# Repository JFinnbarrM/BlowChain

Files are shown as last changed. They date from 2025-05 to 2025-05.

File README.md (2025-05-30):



# BlowChain: LockBox

Authors: James McAuley, Niall Waller, Dhanan Balasaravanan

Oizys - Gold

Topic: Tamper-Proof Secure-Logging Lock-Box

## Overview

Blowchain proposes an advanced digital lockbox, combining environmental sensing, offline architecture, and blockchain based accountability to remove user error from lockbox security

### System Architecture: 
- Mobile Node: Nordic Thingy 52 - The Volatile Organic Compound sensor node located inside the box, this monitors environmental parameters time and off-gassing of volatile organic compounds. 

- Mobile Node: disco_l475_iot1 - The tampering node is located inside the box with a seperate battery, this monitors environmental parameters such as magnometer and accelerometer. 

- Base Node: Receives BLE packets and uploads the data to a secure offline blockchain, checks users, inputted passwords, sensor thresholds and sends it by GATT to the PC.

- M5Core2 Display Unit: Displays a login UI with interactive buttons for each digit to enter. If the user inputs the code correctly they gain access to the lockbox.  

- Desktop Dashboard: Provides a more detailed interface for visualizing historical and live data from the VOC supply. 

- Actuator: Opens and locks the box when receving signals from the base node.

Key Features:
- Real-time BLE communication - GATT Services & Observer/Broadcaster. 
- Secure data logging using blockchain technology.
- Display UI integration with real time feedback.
- Multi-platform visualization (M5Core2, Desktop).
- Multiple sensor from different boards acting on the same system.

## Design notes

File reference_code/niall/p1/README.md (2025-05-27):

# CSSE4011 Prac 1
### _Introduction to Zephyr RTOS and ~~Bootloader~~_

#### **Niall Waller - s45819397 - Partner B**

---
## Folder Structure
repo/mycode/apps
* p1
    * t1
        * boards
            * nucleo_l496zg.overlay
        * src
            * headers.h
            * main.c
        * CMakeLists.txt
        * prj.conf
    * t2
        * boards
            * nucleo_l496zg.overlay
        * src
            * headers.h
            * main.c
        * CMakeLists.txt
        * prj.conf
    * t3
        * boards
            * nucleo_l496zg.overlay
        * src
            * headers.h
            * main.c
        * CMakeLists.txt
        * prj.conf

---
## Design Task 1
### Functionality
Full functionality achieved. The program uses a thread to generate a random number 8 digits long every 2 seconds and then passes it to a message queue primitive where it is retrieved by another thread which displays it to the terminal. The random numbers are generated using a hardware entropy device.

### Instructions
1. Assuming access to the repo folder and device USB connection onto a linux terminal in VS Code.
2. You can open a minicom terminal to view serial output using 'minicom -D /dev/ttyACM*'.
3. To build the design task use 'west build -p -b nucleo_l496zg mycode/apps/p1/t1'.
4. To flash the design task onto the device use 'west flash --runner jlink'.
5. Watch the minicom terminal for serial outputs of the random number generation every 2 seconds.
6. To see thread behaviour run the build command with the additional flags '-- -DCONFIG_QEMU_ICOUNT=n -DCONFIG_THREAD_ANALYZER=y -DCONFIG_THREAD_ANALYZER_USE_PRINTK=y -DCONFIG_THREAD_ANALYZER_AUTO=y -DCONFIG_THREAD_ANALYZER_AUTO_INTERVAL=10 -DCONFIG_THREAD_NAME=y'.

---
## Design Task 2
### Functionality
Full functionality achieved. The program uses a thread to cycle through the 8 colours in order, storing the desired colour in a message queue where another thread accesses it and activates the required GPIO pins accordingly. The setup makes use of the given NAND gate chip as a driver, and also utilises a pwm pin to control the colour and brightness of the RGB LED.

### Instructions
#### Hardware
Refer to the [ST Nucleo-L496ZG Pin Diagram](https://os.mbed.com/platforms/ST-Nucleo-L496ZG/) and [74HC03 Datasheet](https://www.ti.com/lit/ds/symlink/sn74hc03.pdf?ts=1741926828114&ref_url=https%253A%252F%252Fau.mouser.com%252F) for pin labels and connections.
1. Use a ~220 ohm resistor between the chips VCC and each of the LEDs RGB terminals to pull them up to defualt high.
2. Connect the PWM pin (PA_0) to an input of three different NAND gates on the chip.
3. Connect the RED pin (PF_0), GREEN pin (PF_1) and BLUE pin (PF_2) to the other inputs.
4. Connect the outputs of each of the three NAND gates with its respective terminal on the RGB LED.
5. Connect the GND pin on the chip to a ground terminal on the board and the GND pin on the RGB LED.
6. Connect the VCC pin on the chip to a 3V3 or 5V terminal on the board.

#### Code
1. Assuming access to the repo folder and device USB connection onto a linux terminal in VS Code.
2. You can open a minicom terminal to view serial output using 'minicom -D /dev/ttyACM*'.
3. To build the design task use 'west build -p -b nucleo_l496zg mycode/apps/p1/t1'.
4. To flash the design task onto the device use 'west flash --runner jlink'.
5. Watch the LED cycle through 8 different colours.

---
## Design Task 3
### Functionality
Full functionality achieved. The program opens a command line interface shell with the user over the sereal uart connection. From here the user has access to a command that can display the system uptime, and a command to set and toggle two of the on board LEDs. The user will also be able to see configured log messages relevant to the interface and these functions.

#### Instructions
1. Assuming access to the repo folder and device USB connection onto a linux terminal in VS Code.
2. Open a minicom terminal to view serial output using 'minicom -D /dev/ttyACM*'.
3. To build the design task use 'west build -p -b nucleo_l496zg mycode/apps/p1/t1'.
4. To flash the design task onto the device use 'west flash --runner jlink'.
5. The command line interface shell with the board will load into the minicom terminal.
6. Type the command 'help' to get a list of commands you can use from this shell interface, including two custom ones:
   1. time: allows you to view the current uptime of the system.
   2. led: allows you to set and toggle two of the boards led's
   
---
# References
---
1: Zephyr Code (including examples).

_Manually searched through for similar functionality cases._
_Searched using 'grep -r' for function usage examples._

2: Zephyr Documentation.

_Able to manually search for desired outcomes leading to the required functions._

3: Zephyr Api.

_Provided greater detail on function use and implimentation as well as providing a linking to other useful functions._

4: https://docs.zephyrproject.org/latest/boards/st/nucleo_l496zg/doc/index.html

_Zephyr Nucleo-L496ZG overview documentation provided general knowledge._

5: https://www.st.com/resource/en/user_manual/dm00368330.pdf

_Datasheet for the Nucleo-L496ZG board provided general knowledge._

---
1.1: zephyr/tests/subsys/random/rng/src/main.c

_Only provided sample code of rng I could find._

1.2: https://docs.zephyrproject.org/latest/kernel/services/index.html

_Guide on different methods of communication between threads._

1.3: https://docs.zephyrproject.org/latest/doxygen/html/group__msgq__apis.html#ga54a5cdcaea2236c383ace433fedc0d39

_API documentation for creating and using message queues._

1.4: zephyr/doc/kernel/services/data_passing/message_queues.rst

_Additional information with examples of how to create and use message queueus._

1.5: https://docs.zephyrproject.org/latest/kernel/services/threads/index.html

_Guide to the creation and usage of threads._

1.6: https://docs.zephyrproject.org/latest/doxygen/html/group__random__api.html#details

_API documentation specifying functions that can generate randomness_.

1.7: https://docs.zephyrproject.org/latest/services/crypto/random/index.html

_Guide on random number generation._

---
2.1: https://www.youtube.com/watch?v=nHu3_K9OrMg

_General tutorial on how to set up GPIO and PWM pin access using device trees._
_The best way to use a GPIO pin as an output is to configure it as an LED with 'compatible = "gpio-leds";'._
_Code for accessing and using pins is depreciated (video is 3 years old)._

2.2: /zephyr/samples/basic/blinky

_Blinky provided a perfect example on how to use GPIO pins with 'GPIO_DT_SPEC_GET' and 'gpio_pin_configure_dt' and 'gpio_pin_toggle_dt'. This directed me to the 'gpio_dt_spec' datatype._

2.3: https://docs.zephyrproject.org/latest/doxygen/html/group__gpio__interface.html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

_Here I discovered 'gpio_pin_set_dt' and 'GPIO_DT_SPEC_GET_BY_IDX' as well as formalised my knowledge on the functions used by blinky._

2.4: build/zephyr/zephyr.dts

_Looked at blinkys compiled zephyr.dts device tree for example on how its on board LED devices are configured. Copied this format with aliases and an &led node reference in my .overlay file and then checked that it had correctly transferred to the device tree afterwards._
P

2.5: https://www.justfreetools.com/en/rgb-color

_Used to determine RGB requirements to produce the required colours._

2.6 https://os.mbed.com/platforms/ST-Nucleo-L496ZG/

_Detailed and easy to read pin diagram of the board, pin selection and referencing._

2.7 https://www.ti.com/lit/ds/symlink/sn74hc03.pdf?ts=1741926828114&ref_url=https%253A%252F%252Fau.mouser.com%252F

_Datasheet for the NAND gate chip assisted with wiring._

2.8 https://www.geeksforgeeks.org/enumeration-enum-c/

_Provided background knowledge and examples on the use of enums in C programming._

2.9 zephyr/samples/basic/blinky_pwm

_Example used and adapted to create pwm device tree overlay and access/set the pin._

---
3.1 https://docs.zephyrproject.org/latest/services/shell/index.html#shell-api

_Guide to using the zephyr shell._
_Gives a simple command handler implimentation._

3.2 https://docs.zephyrproject.org/apidoc/latest/group__shell__api.html

_Details the implimentation of functions used for the zephyr shell._

3.3 zephyr/samples/subsys/shell/shell_module

_Provided code examples for creating commands for the zephyr shell._

3.4 https://docs.zephyrproject.org/latest/kernel/services/timing/clocks.html

_Guide to kernal timing access._

3.5 https://docs.zephyrproject.org/apidoc/latest/group__clock__apis.html#gae3e992cd3257c23d5b26d765fcbb2b69

_Details the implimentation of functions used for kernal timing access and modification._

3.6 https://docs.zephyrproject.org/latest/services/logging/index.html#logging-kconfig

_Zephyr documentation guide on Logging._

---

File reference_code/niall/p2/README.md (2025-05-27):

# CSSE4011 Prac 2
### _Sensor Processing, Logging and Viewing_

#### **Niall Waller - s45819397 - Partner B**

---
## Folder Structure
```
mycode/p2
├── README.md
├── t1
│   ├── mylib_clock
│   │   ├── CMakeLists.txt
│   │   ├── Kconfig
│   │   ├── include
│   │   │   └── mylib_clock_rtcc.h
│   │   ├── src
│   │   │   └── mylib_clock_rtcc.c
│   │   └── zephyr
│   │       └── module.yml
│   └── tapp
│       ├── CMakeLists.txt
│       ├── prj.conf
│       └── src
│           └── main.c
├── t2
│   ├── mylib_sensors
│   │   ├── CMakeLists.txt
│   │   ├── Kconfig
│   │   ├── boards
│   │   │   └── sltb004a.overlay
│   │   ├── include
│   │   │   ├── mylib_sensors_bmp280.h
│   │   │   ├── mylib_sensors_si1133.h
│   │   │   └── mylib_sensors_si7021.h
│   │   ├── src
│   │   │   ├── board_init.c
│   │   │   ├── mylib_sensors_bmp280.c
│   │   │   ├── mylib_sensors_si1133.c
│   │   │   └── mylib_sensors_si7021.c
│   │   └── zephyr
│   │       └── module.yml
│   └── tapp
│       ├── CMakeLists.txt
│       ├── boards
│       │   └── sltb004a.overlay
│       ├── prj.conf
│       └── src
│           └── main.c
├── t3
│   ├── mylib_shell
│   │   ├── CMakeLists.txt
│   │   ├── Kconfig
│   │   ├── include
│   │   │   └── mylib_shell_globalsh.h
│   │   ├── src
│   │   │   ├── mylib_shell_clock.c
│   │   │   └── mylib_shell_sensors.c
│   │   └── zephyr
│   │       └── module.yml
│   └── tapp
│       ├── CMakeLists.txt
│       ├── boards
│       │   └── sltb004a.overlay
│       ├── prj.conf
│       └── src
│           └── main.c
├── t4
│   ├── mylib_sampling
│   │   ├── CMakeLists.txt
│   │   ├── Kconfig
│   │   ├── boards
│   │   │   └── sltb004a.overlay
│   │   ├── include
│   │   │   ├── mylib_sampling_button.h
│   │   │   ├── mylib_sampling_json.h
│   │   │   └── mylib_sampling_thread.h
│   │   ├── src
│   │   │   ├── mylib_sampling_button.c
│   │   │   ├── mylib_sampling_json.c
│   │   │   ├── mylib_sampling_shell.c
│   │   │   └── mylib_sampling_thread.c
│   │   └── zephyr
│   │       └── module.yml
│   └── tapp
│       ├── CMakeLists.txt
│       ├── boards
│       │   └── sltb004a.overlay
│       ├── prj.conf
│       └── src
│           └── main.c
├── t5
│   ├── mylib_logfiles
│   │   ├── CMakeLists.txt
│   │   ├── Kconfig
│   │   ├── include
│   │   ├── src
│   │   └── zephyr
│   │       └── module.yml
│   └── tapp
│       ├── CMakeLists.txt
│       ├── boards
│       │   └── sltb004a.overlay
│       ├── prj.conf
│       └── src
│           └── main.c
└── t7
    ├── mylib_guipipe
    │   ├── CMakeLists.txt
    │   ├── Kconfig
    │   ├── boards
    │   │   └── sltb004a.overlay
    │   ├── include
    │   ├── src
    │   └── zephyr
    │       └── module.yml
    └── tapp
        ├── CMakeLists.txt
        ├── boards
        │   └── sltb004a.overlay
        ├── prj.conf
        └── src
            └── main.c
```
---
## Test App Project Building Instructions.
1. Assuming access to the repo folder and device USB connection onto a linux terminal in VS Code.
2. You can open a minicom terminal to view serial output using `minicom -D /dev/ttyACM*`.
3. To build the design task test app use `west build -p -b sltb004a mycode/apps/p1/t#/tapp`.
4. To flash the design task onto the device use `west flash --runner jlink`.
5. Done!

---
## Design Task 1
### Functionality
Full functionality achieved. Creates a library that allows reading from and writing to the hardware real time clock (and calendar).

### Instructions
To use the library:

1) Add this to your projects CMakeLists.txt file:
```
set(ENV{EXTRA_ZEPHYR_MODULES}
    "/home/directory/path/.../to/mylib_clock"
)
```
Note: More custom library modules can be added with a ";" seperator.

2) In your prj.conf set `CONFIG_MYLIB_CLOCK=y`.

3) Add header files.
```
#include <mylib_clock_rtcc.h>
```

You can now use the library. See the header file for function usage specifics.

Hint: Try building the t1/tapp project for an example!

---
## Design Task 2
### Functionality
Full functionality achieved for 3/4 sensor readings. Creates a library that uses threads to interface with hardware sensors allowing you to read from them without taking up main program resources.

### Instructions
To use the library:

1) Add this to your projects CMakeLists.txt file:
```
set(ENV{EXTRA_ZEPHYR_MODULES}
    "/home/directory/path/.../to/mylib_sensors"
)
```
Note: More custom library modules can be added with a ";" seperator.

2) In your prj.conf set `CONFIG_MYLIB_SENSORS=y`.

3) Add header files.
```
#include <mylib_sensors_bmp280.h>
#include <mylib_sensors_si1133.h>
#include <mylib_sensors_si7021.h>
```

4) Copy the boards folder (containing the sltb004a.overlay) file into your project directory.

You can now use the library. See the header file for function usage specifics.
Hint: Try building the t2/tapp project for an example!

---
## Design Task 3
### Functionality
Full functionality achieved. Shell commands can interface with both the clock and sensor libraries.

#### Instructions
To use the library (this one depends on other libraries!):

1) Add this to your projects CMakeLists.txt file:
```
set(ENV{EXTRA_ZEPHYR_MODULES} 
    "/home/directory/path/.../to/mylib_clock;/home/directory/path/.../to/mylib_sensors;/home/directory/path/.../to/mylib_shell;/home/directory/path/.../to/mylib_sampling"
)
```
Note: More libraries can be added with a ";" seperator.

2) In your prj.conf set:
```
CONFIG_MYLIB_CLOCK=y
CONFIG_MYLIB_SENSORS=y

CONFIG_MYLIB_SHELL=y
```

3) You will automatically have access to the shell commands. But if you want access to the shell instance used by the library called "sh_global":
```
#include <mylib_shell_globalsh>
```

4) Copy the boards folder (containing the sltb004a.overlay) file into your project directory.

You can now use the library. Type `help` into the CLI for command specifics.
Hint: Try building the t3/tapp project for an example!

---
## Design Task 4
### Functionality
Full functionality achieved. Continuous sampling can be configured using the shell. Contiuous sampling is started/stopped with a button on the board. Each sample is configured into a JSON string which can be viewed in the shell.

#### Instructions
To use the library (this one depends on other libraries!):

1) Add this to your projects CMakeLists.txt file:
```
set(ENV{EXTRA_ZEPHYR_MODULES} 
    "/home/directory/path/.../to/mylib_sensors;/home/directory/path/.../to/mylib_clock;/home/directory/path/.../to/mylib_samples"
)
```
Note: More custom library modules can be added with a ";" seperator.

2) In your prj.conf set:
```
CONFIG_MYLIB_SHELL=y
CONFIG_MYLIB_CLOCK=y
CONFIG_MYLIB_SENSORS=y

CONFIG_MYLIB_SAMPLING=y
```

3) Add header files if needed.

4) Copy the boards folder (containing the sltb004a.overlay) file into your project directory.

You can now use the library. Type `help` into the CLI for command specifics.
NOTE: THIS LIBRARYS TEST APP (TAPP) IS THE FINAL DEMO BUILD.

---
## Design Task 5
### Functionality
#### Instructions

---
## Design Task 7
### Functionality
#### Instructions

---
# References
---
## Task 1

1.1: https://www.silabs.com/documents/public/reference-manuals/efr32xg12-rm.pdf

_Wireless Gecko Reference Manual for the EFR32 chip used on the sltb004a thunderboard._
_Used to set and get from RTCC registers._

1.2: https://docs.zephyrproject.org/latest/doxygen/html/structrtc__time.html

_The rtc\_time struct reference documentation to make my library compatible with the zephyr RTC library._

1.3: modules/hal/silabs/gecko/emlib/inc/em_rtcc.h

_HAL library used to configure, get, and set from the RTCC registers._

1.3: modules/hal/silabs/gecko/emlib/inc/em_rtcc.h

_library used to check external low frequency clock was being used for RTCC._

1.4: https://edstem.org/au/courses/22383/discussion/2517796

_Ed post by Sam Kwort about file structure and CMakeLists.txt code for libraries._

1.5: https://docs.zephyrproject.org/latest/develop/modules.html#modules-without-west

_How to create modules(libraries)._

1.6: https://docs.zephyrproject.org/latest/develop/env_vars.html#env-vars

_Explains how to set the EXTRA\_ZEPHYR\_MODULES environment variable for adding your own modules_.
To set it for prac 2:
+ cp mycode/p2/.zepyrrc ~/.zephyrrc
+ source zephyr/zephyr-env.sh
Check with echo $EXTRA_ZEPHYR_MODULES

1.7: https://cmake.org/cmake/help/latest/index.html

_For understanding Cmake._

1.8: https://docs.zephyrproject.org/latest/build/cmake/index.html

_For understanding how zephyr uses CMake._

1.9: https://github.com/zephyrproject-rtos/example-application/blob/main/lib/custom/CMakeLists.txt

_Example application with a library._

1.10: https://docs.zephyrproject.org/latest/build/kconfig/index.html

_Guide to using Kconfig files for configs instead of the .config file._

1.11: https://www.tutorialspoint.com/c_standard_library/c_function_sscanf.htm

_Used to understand the sscanf() function for cmd argument parsing._

---
## Task 2

2.1: https://cmake.org/cmake/help/latest/manual/cmake-language.7.html#lists

_How to list multiple variables in a CMake environment variable (seperate with ';')._

2.2: https://www.silabs.com/documents/public/data-sheets/efr32mg12-datasheet.pdf

_EFR32MG12 Gecko Multi-Protocol Wireless SoC Family Data Sheet._

2.3: https://www.silabs.com/documents/public/schematic-files/BRD4166A-D00-schematic.pdf

_Board schematic._

2.4: https://edstem.org/au/courses/22383/discussion/2527683

_Sam's helpful ed post._

2.5: https://download.mikroe.com/documents/datasheets/Si1133.pdf

_Datasheet for si1133 (UV and Light sensor)._

2.6: https://www.silabs.com/documents/public/data-sheets/Si7021-A20.pdf

_Datasheet for si7021 (Humidity and Tempurature sensor)_.

2.7: https://www.bosch-sensortec.com/media/boschsensortec/downloads/datasheets/bst-bmp280-ds001.pdf

_Datasheet for bmp280 (Temp and Pressure sensor)._

2.8: https://docs.zephyrproject.org/latest/hardware/pinctrl/index.html

_How to name pins on the dt so that they work by default._
_Both the gas and environment sensors need the same I2C bus so have to replace the gas sensor as default or use dynamic pin control to get them to both work._

2.9: zephyr/samples/sensor/bme280

_Example usage of the bmp sensor._
_Got it working by using ed post #178 by Sam which involved setting the device tree right, using an initialising function to set the supply gpios and then removing humidity as the bmp280 doesnt have it unlike the bme280 the sample was origionally made for._

3.10: https://docs.zephyrproject.org/latest/hardware/peripherals/sensor/index.html

_How to program for sensors._

3.11: https://docs.zephyrproject.org/latest/doxygen/html/group__math__printing.html

_How to convert q31 values for printing._

3.11: https://docs.zephyrproject.org/apidoc/latest/group__spsc__lockfree.html

_SPSC message passing primitive API._

---
## Task 3

3.1: https://docs.zephyrproject.org/latest/services/shell/index.html#commands

_How to create and register shell commands with subcommands (its a heck of a lot easier than what I was doing previously)._

---
## Task 4

4.1: https://docs.zephyrproject.org/latest/doxygen/html/group__atomic__apis.html

_Atomic values._

4.2: ./zephyr/samples/basic/button

_Example of using a button._

4.3: https://github.com/zephyrproject-rtos/zephyr/blob/main/drivers/input/input_gpio_keys.c

_Driver for gpio-keys which the device tree has listed as compatible for the button nodes on my board. Its functions are used in the basic button example._

4.4: https://docs.zephyrproject.org/apidoc/latest/group__json.html

_Zephyr JSON API documentation._

4.5: ./zephyr/samples/net/secure_mqtt_sensor_actuator/src/mqtt_client.c

_Example of reading sensor values and encoding them in JSON format._

4.6: https://docs.zephyrproject.org/latest/kernel/memory_management/heap.html

_THANKYOU MALLOC._
_I needed to malloc for dynamically determined arrays._
---
## Task 5

5.1: 

---
## Task 7

7.1: 

---

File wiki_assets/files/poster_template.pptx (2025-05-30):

## BlowChain: Tamper-Proof Secure-Logging Lock-Box

- General Hints & Tips
- Do not change the colour/size/logos/positioning of the Slide Master.
- This is a standard format across all Innovation Expo posters.
- Do not add other corporate logos. This is an infringement of copyright, unless you have express permission to do so.
- Do use this space as creatively as you wish.
- Avoid using large background colours – doesn’t print well.
- Stick to the basic fonts & sizes (left) – these read clearly. If you need to reduce the text size, you are trying to put too much on your poster.
- As a check, print “scaled to fit” onto A4 and read at arms length.
- Save your poster as you work on it.
- You shouldn’t need to change the sizing of this file, it should already be landscape format with width: 41cm and height: 28.7 cm (A3 with 5 mm borders all around).
- The title may look to close to the top edge – don’t be tempted to change it. It allows for the extra 5mm from the printing.

GitHub Wiki:
Subheadings – Helvetica Neue Bold 14pt
Body Text – Helvetica Neue 14pt (min 12pt)
Don’t have the above fonts installed?
Substitutes for Bodoni MT:
Didot on Apple
or Times New Roman (Apple & Windows)
Substitutes for Helvetica Neue:
Helvetica (Apple)
or Arial (Apple & Windows)

Niall Waller, James McAuley, Dhanan Balasaravanan

What's The Problem ?
Traditional Lockboxes:
- Single shared access code → weak security & no accountability.
- Manual logs → unreliable auditing.
Digital Alternatives:
- Internet-dependent → vulnerable to remote attacks.
- Centralized databases → risk of data modification breaches.

What’s Our Solution ?
BlowChain proposes an advanced digital lockbox, combining environmental sensing, offline architecture, and blockchain based accountability to remove user error from lockbox security.

How Does it Work ?

Feature | Benefit
Human Presence Detection (CO₂ + particle sensors) | Prevents spoofing by verifying access attempt is by a human.
Blockchain Immutable Logs | Tamper-proof record of all events.
Dynamic Access Tokens (NFT-based credentials) | Time-bound, revocable permissions per user (no static codes).
Tamper Detection (Magnetometer trigger) | Alerts + logs forced entry attempts in real time.
Offline-First Design (BLE-only to base station) | No direct internet exposure → immunity to remote hacking.

What Did We Found Out ?
- Human interaction met KPI goals with registering sensor happening 98% of the time.
- GATT BLE Communication is One-To-One thus we used 1 GATT service with multiple observation/advertisers.
- Blockchain validation and performance is limited by the storage space, most blocks were
- Minting and transaction loading happened every 5 seconds with 3 transactions possible per block.

Who Needs It ?
- Real estate (secure property showings).
- Rental units (self-check-in with logs).
- Shared facilities (granular access control).
- Companies that create or access intellectual property that needs to be stored.

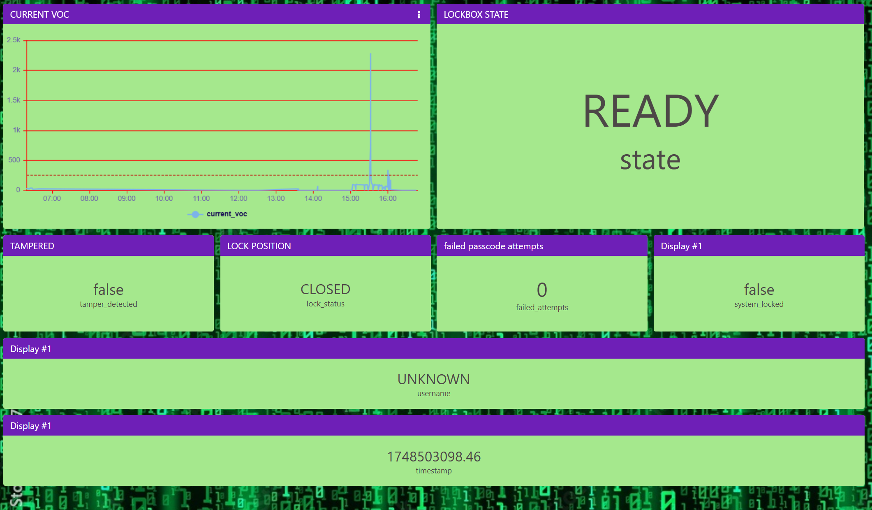
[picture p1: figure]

References & Acknowledgments
- Building Blockchain Projects – Narayan Prusty.
- Zephyr Documentation – especially Bluetooth.
- Thank you Matt, Michael & especially all the tutors for the experience.

## TITLE OF YOUR PROJECT (BODONI MT 48PT)

Your Names and Team ID (A, B, etc) (Helvetica Neue 24pt)

- MAIN HEADINGS – BODONI MT 18PT ALL CAPS
- Subheadings – Helvetica Neue Bold 14pt
- Body Text – Helvetica Neue 14pt (min 12pt)
- Don’t have the above fonts installed?
- Substitutes for Bodoni MT:
- Didot on Apple
- or Times New Roman (Apple & Windows)
- Substitutes for Helvetica Neue:
- Helvetica (Apple)
- or Arial (Apple & Windows)

- General Hints & Tips
- Do not change the colour/size/logos/positioning of the Slide Master.
- This is a standard format across all Innovation Expo posters.
- Do not add other corporate logos. This is an infringement of copyright, unless you have express permission to do so.
- Do use this space as creatively as you wish.
- Avoid using large background colours – doesn’t print well.
- Stick to the basic fonts & sizes (left) – these read clearly. If you need to reduce the text size, you are trying to put too much on your poster.
- As a check, print “scaled to fit” onto A4 and read at arms length.
- Save your poster as you work on it.
- You shouldn’t need to change the sizing of this file, it should already be landscape format with width: 41cm and height: 28.7 cm (A3 with 5 mm borders all around).
- The title may look to close to the top edge – don’t be tempted to change it. It allows for the extra 5mm from the printing.

## BlowChain: Tamper-Proof Secure-Logging Lock-Box

- General Hints & Tips
- Do not change the colour/size/logos/positioning of the Slide Master.
- This is a standard format across all Innovation Expo posters.
- Do not add other corporate logos. This is an infringement of copyright, unless you have express permission to do so.
- Do use this space as creatively as you wish.
- Avoid using large background colours – doesn’t print well.
- Stick to the basic fonts & sizes (left) – these read clearly. If you need to reduce the text size, you are trying to put too much on your poster.
- As a check, print “scaled to fit” onto A4 and read at arms length.
- Save your poster as you work on it.
- You shouldn’t need to change the sizing of this file, it should already be landscape format with width: 41cm and height: 28.7 cm (A3 with 5 mm borders all around).
- The title may look to close to the top edge – don’t be tempted to change it. It allows for the extra 5mm from the printing.

GitHub Wiki:
Subheadings – Helvetica Neue Bold 14pt
Body Text – Helvetica Neue 14pt (min 12pt)
Don’t have the above fonts installed?
Substitutes for Bodoni MT:
Didot on Apple
or Times New Roman (Apple & Windows)
Substitutes for Helvetica Neue:
Helvetica (Apple)
or Arial (Apple & Windows)

Niall Waller, James McAuley, Dhanan Balasaravanan

What’s Our Solution ?
BlowChain proposes an advanced digital lockbox, combining environmental sensing, offline architecture, and blockchain based accountability to remove user error from lockbox security.

How Does it Work ?

What's The Problem ?
Traditional Lockboxes:
- Single shared access code → weak security & no accountability.
- Manual logs → unreliable auditing.
Digital Alternatives:
- Internet-dependent → vulnerable to remote attacks.
- Centralized databases → risk of data modification breaches.

Feature | Benefit
Human Presence Detection (CO₂ + particle sensors) | Prevents spoofing by verifying access attempt is by a human.
Blockchain Immutable Logs | Tamper-proof record of all events.
Dynamic Access Tokens (NFT-based credentials) | Time-bound, revocable permissions per user (no static codes).
Tamper Detection (Magnetometer trigger) | Alerts + logs forced entry attempts in real time.
Offline-First Design (BLE-only to base station) | No direct internet exposure → immunity to remote hacking.

Who Needs It ?
- Real estate (secure property showings).
- Rental units (self-check-in with logs).
- Shared facilities (granular access control).
- Companies that create or access intellectual property that needs to be stored.

## BlowChain: Tamper-Proof Secure-Logging Lock-Box

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

GitHub Wiki:
Subheadings – Helvetica Neue Bold 14pt
Body Text – Helvetica Neue 14pt (min 12pt)
Don’t have the above fonts installed?
Substitutes for Bodoni MT:
Didot on Apple
or Times New Roman (Apple & Windows)
Substitutes for Helvetica Neue:
Helvetica (Apple)
or Arial (Apple & Windows)

Niall Waller, James McAuley, Dhanan Balasaravanan

How Does it Work ?

What's The Problem ?
Traditional Lockboxes:
- Single shared access code → weak security & no accountability.
- Manual logs → unreliable auditing.
Digital Alternatives:
- Internet-dependent → vulnerable to remote attacks.
- Centralized databases → risk of data modification breaches.

Who Would We Like To Thank ?
- Ourselves
- …
- …

What’s Our Solution ?
BlowChain proposes an advanced digital lockbox, combining environmental sensing, offline architecture, and blockchain based accountability to remove user error from lockbox security.

Who Needs It ?
- Real estate (secure property showings).
- Rental units (self-check-in with logs).
- Shared facilities (granular access control).
- Companies that create or access intellectual property that needs to be stored.

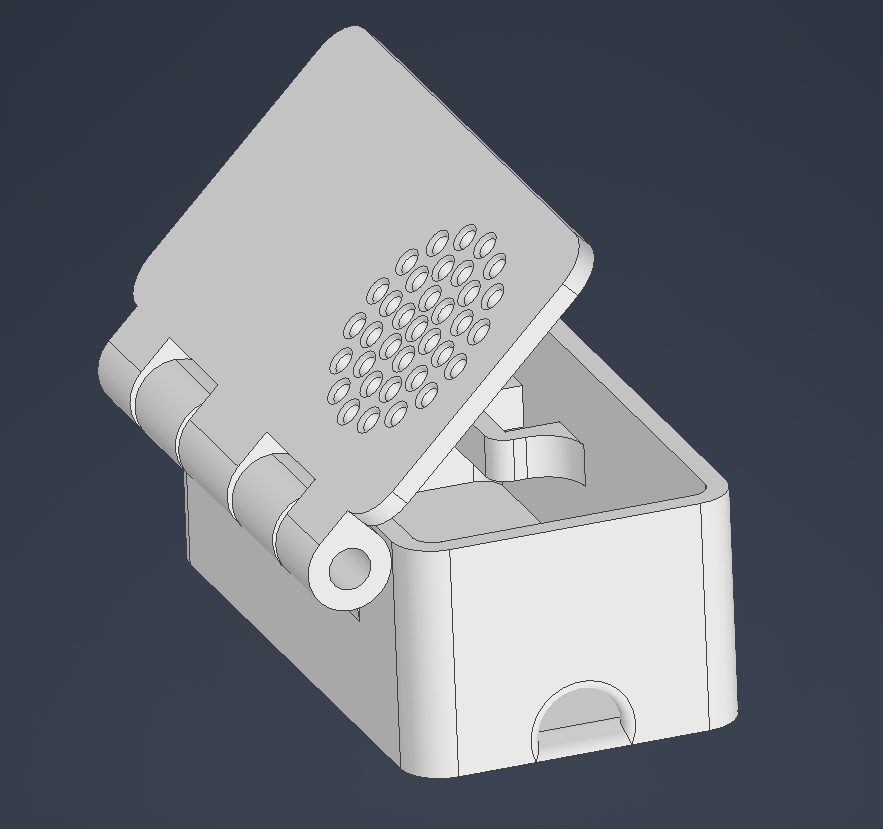
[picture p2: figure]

Feature | Benefit
Human Presence Detection (CO₂ + particle sensors) | Prevents spoofing by verifying access attempt is by a human.
Blockchain Immutable Logs | Tamper-proof record of all events.
Dynamic Access Tokens (NFT-based credentials) | Time-bound, revocable permissions per user (no static codes).
Tamper Detection (Magnetometer trigger) | Alerts + logs forced entry attempts in real time.
Offline-First Design (BLE-only to base station) | No direct internet exposure → immunity to remote hacking.

What Did We Found Out ?
- …
- …
- …

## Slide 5

## BlowChain: Tamper-Proof Secure-Logging Lock-Box

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

Niall Waller, James McAuley, Dhanan Balasaravanan

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

How Does it Work ?

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

What Did We Found Out ?
- Human interaction met KPI goals with registering sensor happening 98% of the time.
- GATT BLE Communication is One-To-One thus we used 1 GATT service with multiple observation/advertisers.
- Blockchain validation and performance is limited by the storage space, most blocks were
- Minting and transaction loading happened every 5 seconds with 3 transactions possible per block.

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

References & Acknowledgments
- Building Blockchain Projects – Narayan Prusty.
- Zephyr Documentation – especially Bluetooth.
- Thank you Matt, Michael & especially all the tutors for the experience.

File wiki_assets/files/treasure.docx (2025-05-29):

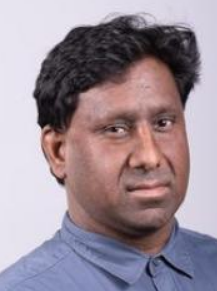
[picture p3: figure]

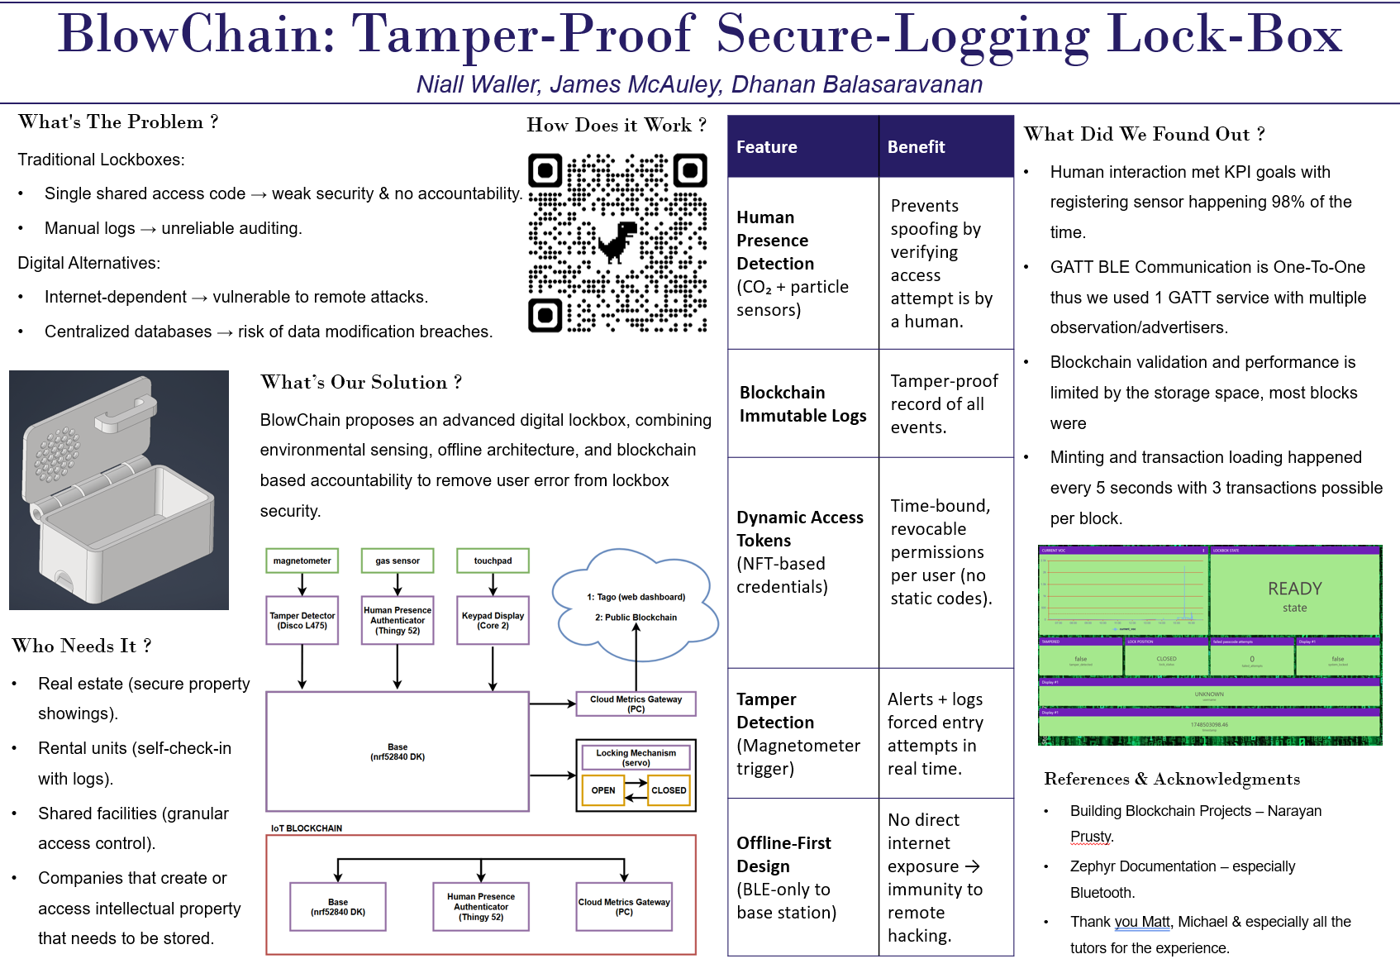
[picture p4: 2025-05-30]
wiki_assets/poster.png

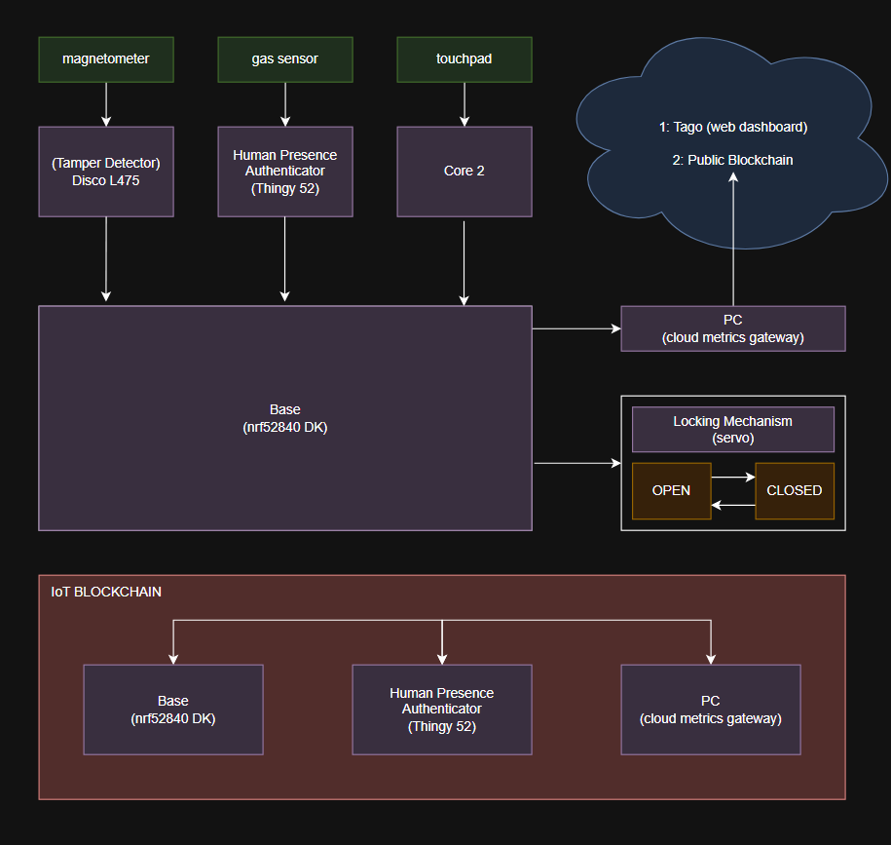
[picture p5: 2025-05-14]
wiki_assets/LockBox_BlockDiagram.png

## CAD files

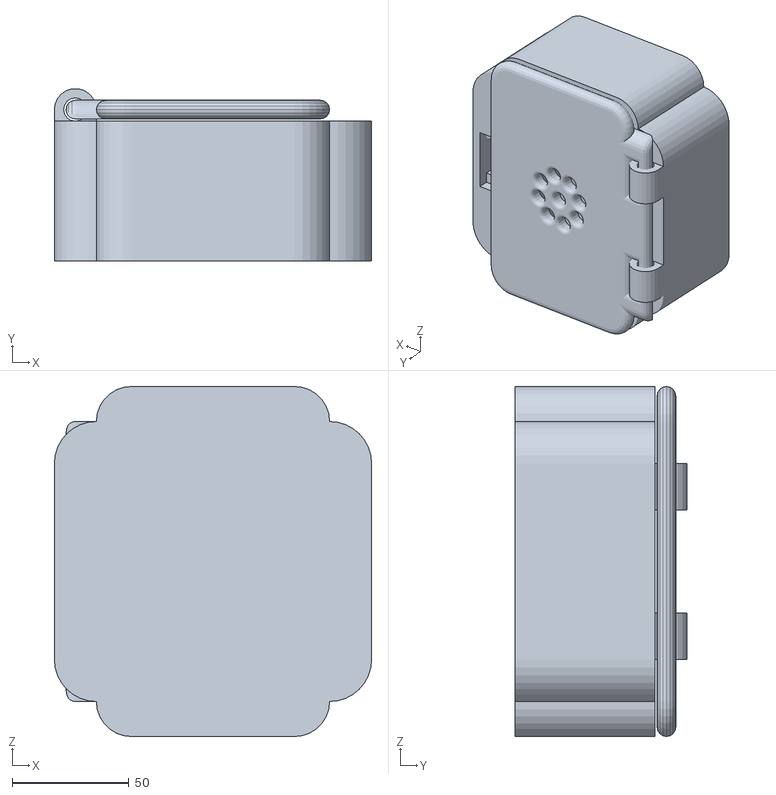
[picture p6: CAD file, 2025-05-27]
wiki_assets/files/inventor/one/assembly_p1.stl
136.0 x 73.9 x 150.0

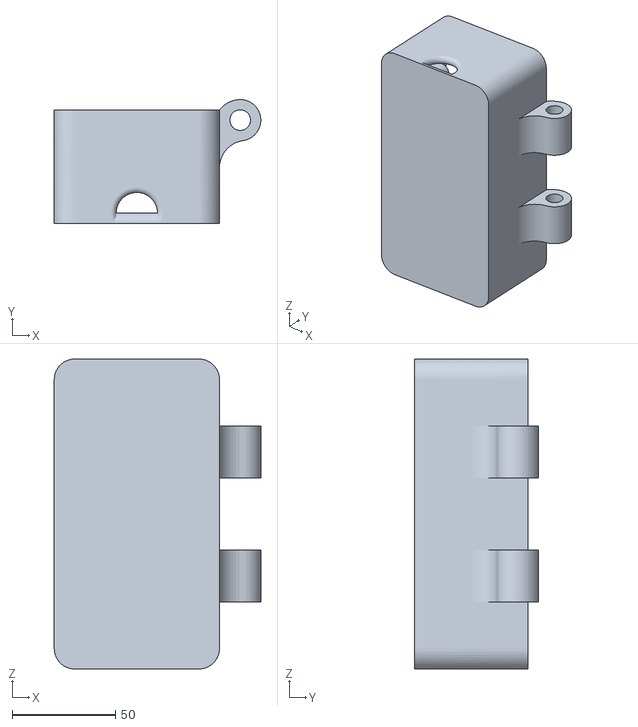
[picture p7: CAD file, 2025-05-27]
wiki_assets/files/inventor/two/box2.stl
100.0 x 60.0 x 150.0

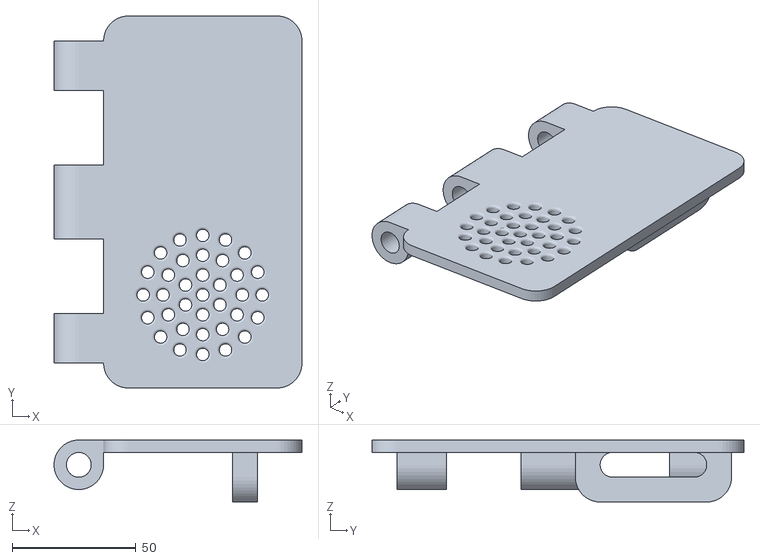
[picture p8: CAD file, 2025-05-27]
wiki_assets/files/inventor/two/lid2.stl
100.0 x 150.0 x 25.0

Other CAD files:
wiki_assets/files/OldVersions/box.0001.ipt
wiki_assets/files/inventor/OldVersions/assembly.0001.iam
wiki_assets/files/inventor/OldVersions/box.0006.ipt
wiki_assets/files/inventor/one/assembly.iam
wiki_assets/files/inventor/one/box.ipt
wiki_assets/files/inventor/one/lid.ipt
wiki_assets/files/inventor/two/OldVersions/assembly2.0004.iam
wiki_assets/files/inventor/two/OldVersions/box2.0004.ipt
wiki_assets/files/inventor/two/OldVersions/lid2.0004.ipt
wiki_assets/files/inventor/two/assembly2.iam
wiki_assets/files/inventor/two/box2.ipt
wiki_assets/files/inventor/two/lid2.ipt

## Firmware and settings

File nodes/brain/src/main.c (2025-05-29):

#include "lock.h"
#include "zephyr/bluetooth/gap.h"
#include <zephyr/kernel.h>
#include <zephyr/device.h>
#include <zephyr/fs/fs.h>
#include <zephyr/fs/littlefs.h>
#include <zephyr/storage/flash_map.h>
#include <zephyr/logging/log.h>
#include <zephyr/shell/shell.h>
#include <zephyr/bluetooth/bluetooth.h>
#include <zephyr/bluetooth/gatt.h>
#include <zephyr/bluetooth/uuid.h>
#include <string.h>
#include <stdio.h>
#include <stdlib.h>

LOG_MODULE_REGISTER(blockchain, LOG_LEVEL_INF);

static char* static_mac_str =  "dc:80:00:00:08:35";

#define MAX_TRANSACTIONS_PER_BLOCK 3
#define MAX_USER_ID_LEN 16
#define MAX_DATA_LEN 32
#define BLOCKCHAIN_FILE "/lfs/chain.dat"
#define MAX_BLOCKS 20
#define HASH_SIZE 8
#define MAX_FAILED_ATTEMPTS 3
#define PASSCODE_LEN 6
#define MAX_BLE_CONNECTIONS 4

// Multi-user support definitions
#define MAX_USERS 10
#define PASSCODE_EXPIRE_TIME_MS (5 * 60 * 1000)  // 5 minutes

#define BT_UUID_LOCKBOX_SERVICE      BT_UUID_DECLARE_16(0x1234)
#define BT_UUID_USERNAME             BT_UUID_DECLARE_16(0xAA01)
#define BT_UUID_BLOCK_INFO           BT_UUID_DECLARE_16(0xBB02)
#define BT_UUID_LOCK_STATUS          BT_UUID_DECLARE_16(0xCC03)
#define BT_UUID_USER_STATUS          BT_UUID_DECLARE_16(0xDD04)
#define BT_UUID_PASSCODE             BT_UUID_DECLARE_16(0xEE05)
#define BT_UUID_VOC_SENSOR           BT_UUID_DECLARE_16(0xFF06)
#define BT_UUID_TAMPER_CONTROL       BT_UUID_DECLARE_16(0x1107)  // NEW: Tamper control

static bool verbose = false;

typedef enum {
    TX_USER_ADDED = 1,
    TX_ACCESS_GRANTED,
    TX_ACCESS_DENIED,
    TX_PRESENCE_DETECTED,
    TX_PASSCODE_GENERATED,
    TX_PASSCODE_VERIFIED,
    TX_PASSCODE_FAILED,
    TX_TAMPER_DETECTED,
    TX_SYSTEM_LOCKED,
    TX_SYSTEM_STARTUP,
    TX_SYSTEM_SHUTDOWN
} transaction_type_t;

typedef enum {
    STATE_READY = 0,
    STATE_PRESENCE_DETECTED,
    STATE_WAITING_PASSCODE,
    STATE_LOCKED,
    STATE_SHUTDOWN
} system_state_t;

typedef enum {
    CLIENT_TYPE_UNKNOWN = 0,
    CLIENT_TYPE_PC,
    CLIENT_TYPE_VOC_SENSOR
} client_type_t;

typedef struct {
    uint32_t timestamp;
    transaction_type_t type;
    char user_id[MAX_USER_ID_LEN];
    char data[MAX_DATA_LEN];
    uint32_t hash;
} simple_transaction_t;

typedef struct {
    uint32_t id;
    uint32_t timestamp;
    uint32_t prev_hash;
    uint32_t nonce;
    uint16_t tx_count;
    simple_transaction_t transactions[MAX_TRANSACTIONS_PER_BLOCK];
    uint32_t block_hash;
} simple_block_t;

typedef struct {
    uint32_t total_blocks;
    uint32_t latest_hash;
    simple_block_t blocks[MAX_BLOCKS];
} blockchain_data_t;

typedef struct {
    system_state_t state;
    char current_passcode[PASSCODE_LEN + 1];
    char current_user[MAX_USER_ID_LEN];
    uint32_t failed_attempts;
    uint32_t passcode_timestamp;
    bool tamper_detected;
    bool system_locked;
    bool system_shutdown;  // NEW: System shutdown flag
} lockbox_state_t;

typedef struct {
    struct bt_conn *conn;
    client_type_t type;
    char identifier[16];
    uint32_t last_activity;
    bool is_active;
    bool voc_notifications_enabled;
    bool status_notifications_enabled;
    bool lock_notifications_enabled;
    bool block_notifications_enabled;
} connection_info_t;

typedef struct {
    char user_id[MAX_USER_ID_LEN];
    char passcode[PASSCODE_LEN + 1]; 
    uint32_t timestamp;
    bool is_active;
} user_entry_t;

typedef struct {
    user_entry_t users[MAX_USERS];
    int active_user_count;
} user_table_t;

// Bluetooth stuff
static const bt_addr_le_t mac_addr_thing = {
    .type = BT_ADDR_LE_RANDOM,
    .a = {.val = {0xFF, 0xAA, 0xFF, 0xAA, 0xFF, 0xDA}}
};

static const bt_addr_le_t mac_addr_disco = {
    .type = BT_ADDR_LE_RANDOM,
    .a = {.val = {0xFF, 0xCC, 0xBB, 0xCC, 0xBB, 0xDA}}
};

static const bt_addr_le_t mac_addr_core = {
    .type = BT_ADDR_LE_RANDOM,
    .a = {.val = {0xFF, 0xCC, 0xBC, 0xBB, 0xAA, 0xDA}}
};

struct sensor_data {
    int x;
    int y;
    int z;
    int xf;
    int yf;
    int zf;
};

static blockchain_data_t g_blockchain;
static lockbox_state_t g_lockbox_state = {0};
static struct k_mutex blockchain_mutex;
static struct k_mutex lockbox_mutex;
static struct k_msgq pending_tx_queue;
static simple_transaction_t pending_tx_buffer[10];
static char current_username[MAX_USER_ID_LEN] = "UNKNOWN";

// Multi-user globals
static user_table_t g_user_table = {0};
static struct k_mutex user_table_mutex;

#define VOC_PRESENCE_THRESHOLD 250
#define MAG_PRESENCE_THRESHOLD 250
#define ACC_PRESENCE_THRESHOLD 250
static connection_info_t connections[MAX_BLE_CONNECTIONS];
static struct k_mutex connections_mutex;

static uint16_t current_voc_value = 0;
static uint32_t last_voc_timestamp = 0;

static uint16_t current_avg_acc_value = 0;
static uint16_t current_avg_mag_value = 0;

// Global shutdown flag for threads
static volatile bool system_shutdown_requested = false;

static int create_genesis_block(void);
static int save_blockchain(void);
static int load_blockchain(void);
static void send_alert_to_dashboard(const char *message);
static int reset_blockchain(void);
static int validate_blockchain(void);
static void trigger_system_shutdown(const char *reason);  // NEW: System shutdown function

// Connection management function declarations
static int find_free_connection_slot(void);
static int find_connection_by_handle(struct bt_conn *conn);
static void update_connection_activity(struct bt_conn *conn);
static client_type_t get_connection_type(struct bt_conn *conn);
static void set_connection_type(struct bt_conn *conn, client_type_t type, const char *identifier);

// Blockchain function declarations
static int add_transaction(transaction_type_t type, const char *user_id, const char *data);

// Multi-user function declarations
static int find_user_index(const char *user_id);
static int find_free_user_slot(void);
static void cleanup_expired_passcodes(void);
static void generate_passcode(const char *user_id);
static bool verify_passcode(const char *user_id, const char *entered_code);

FS_LITTLEFS_DECLARE_DEFAULT_CONFIG(storage);
static struct fs_mount_t blockchain_fs_mount = {
    .type = FS_LITTLEFS,
    .fs_data = &storage,
    .storage_dev = (void *)FIXED_PARTITION_ID(storage_partition),
    .mnt_point = "/lfs",
};

// Forward declarations for GATT handlers
static ssize_t write_voc_sensor(struct bt_conn *conn, const struct bt_gatt_attr *attr,
                               const void *buf, uint16_t len, uint16_t offset, uint8_t flags);
static ssize_t read_voc_sensor(struct bt_conn *conn, const struct bt_gatt_attr *attr,
                                void *buf, uint16_t len, uint16_t offset);
static ssize_t write_username(struct bt_conn *conn, const struct bt_gatt_attr *attr, 
                             const void *buf, uint16_t len, uint16_t offset, uint8_t flags);
static ssize_t read_username(struct bt_conn *conn, const struct bt_gatt_attr *attr,
                            void *buf, uint16_t len, uint16_t offset);
static ssize_t read_block_info(struct bt_conn *conn, const struct bt_gatt_attr *attr,
                              void *buf, uint16_t len, uint16_t offset);
static ssize_t read_lock_status(struct bt_conn *conn, const struct bt_gatt_attr *attr,
                               void *buf, uint16_t len, uint16_t offset);
static ssize_t read_user_status(struct bt_conn *conn, const struct bt_gatt_attr *attr,
                               void *buf, uint16_t len, uint16_t offset);
static ssize_t write_passcode(struct bt_conn *conn, const struct bt_gatt_attr *attr,
                             const void *buf, uint16_t len, uint16_t offset, uint8_t flags);
static ssize_t read_passcode(struct bt_conn *conn, const struct bt_gatt_attr *attr,
                            void *buf, uint16_t len, uint16_t offset);
// NEW: Tamper control handlers
static ssize_t write_tamper_control(struct bt_conn *conn, const struct bt_gatt_attr *attr,
                                   const void *buf, uint16_t len, uint16_t offset, uint8_t flags);
static ssize_t read_tamper_control(struct bt_conn *conn, const struct bt_gatt_attr *attr,
                                  void *buf, uint16_t len, uint16_t offset);

// GATT Service Definition - Updated with tamper control
BT_GATT_SERVICE_DEFINE(lockbox_svc,
    BT_GATT_PRIMARY_SERVICE(BT_UUID_LOCKBOX_SERVICE),
    
    BT_GATT_CHARACTERISTIC(BT_UUID_USERNAME, 
        BT_GATT_CHRC_READ | BT_GATT_CHRC_WRITE,
        BT_GATT_PERM_READ | BT_GATT_PERM_WRITE,
        read_username, write_username, NULL),
        
    BT_GATT_CHARACTERISTIC(BT_UUID_BLOCK_INFO,
        BT_GATT_CHRC_READ,
        BT_GATT_PERM_READ,
        read_block_info, NULL, NULL),
        
    BT_GATT_CHARACTERISTIC(BT_UUID_LOCK_STATUS,
        BT_GATT_CHRC_READ,
        BT_GATT_PERM_READ,
        read_lock_status, NULL, NULL),
        
    BT_GATT_CHARACTERISTIC(BT_UUID_USER_STATUS,
        BT_GATT_CHRC_READ,
        BT_GATT_PERM_READ,
        read_user_status, NULL, NULL),
        
    BT_GATT_CHARACTERISTIC(BT_UUID_PASSCODE,
        BT_GATT_CHRC_READ | BT_GATT_CHRC_WRITE,
        BT_GATT_PERM_READ | BT_GATT_PERM_WRITE,
        read_passcode, write_passcode, NULL),
        
    BT_GATT_CHARACTERISTIC(BT_UUID_VOC_SENSOR,
        BT_GATT_CHRC_READ | BT_GATT_CHRC_WRITE,
        BT_GATT_PERM_READ | BT_GATT_PERM_WRITE,
        read_voc_sensor, write_voc_sensor, NULL),
        
    // NEW: Tamper control characteristic
    BT_GATT_CHARACTERISTIC(BT_UUID_TAMPER_CONTROL,
        BT_GATT_CHRC_READ | BT_GATT_CHRC_WRITE,
        BT_GATT_PERM_READ | BT_GATT_PERM_WRITE,
        read_tamper_control, write_tamper_control, NULL),
);

static const struct bt_data ad[] = {
    BT_DATA_BYTES(BT_DATA_FLAGS, BT_LE_AD_GENERAL | BT_LE_AD_NO_BREDR),
    BT_DATA_BYTES(BT_DATA_NAME_COMPLETE, "SecureLockbox"),
    BT_DATA_BYTES(BT_DATA_UUID16_ALL, 0x34, 0x12),
};

static char* find_user_by_passcode(const char *passcode) {
    static char found_user_id[MAX_USER_ID_LEN];
    
    k_mutex_lock(&user_table_mutex, K_FOREVER);
    
    // Clean up expired passcodes first
    cleanup_expired_passcodes();
    
    for (int i = 0; i < MAX_USERS; i++) {
        if (g_user_table.users[i].is_active && 
            strcmp(g_user_table.users[i].passcode, passcode) == 0) {
            strncpy(found_user_id, g_user_table.users[i].user_id, MAX_USER_ID_LEN - 1);
            found_user_id[MAX_USER_ID_LEN - 1] = '\0';
            k_mutex_unlock(&user_table_mutex);
            return found_user_id;
        }
    }
    
    k_mutex_unlock(&user_table_mutex);
    return NULL;
}

// Multi-user helper functions
static int find_user_index(const char *user_id) {
    for (int i = 0; i < MAX_USERS; i++) {
        if (g_user_table.users[i].is_active && 
            strcmp(g_user_table.users[i].user_id, user_id) == 0) {
            return i;
        }
    }
    return -1;
}

static int find_free_user_slot(void) {
    for (int i = 0; i < MAX_USERS; i++) {
        if (!g_user_table.users[i].is_active) {
            return i;
        }
    }
    return -1;
}

static void cleanup_expired_passcodes(void) {
    uint32_t current_time = k_uptime_get_32();
    
    for (int i = 0; i < MAX_USERS; i++) {
        if (g_user_table.users[i].is_active) {
            uint32_t age = current_time - g_user_table.users[i].timestamp;
            if (age > PASSCODE_EXPIRE_TIME_MS) {
                LOG_INF("Passcode expired for user: %s", g_user_table.users[i].user_id);
                memset(&g_user_table.users[i], 0, sizeof(user_entry_t));
                g_user_table.active_user_count--;
            }
        }
    }
}

// Connection management functions
static int find_free_connection_slot(void) {
    for (int i = 0; i < MAX_BLE_CONNECTIONS; i++) {
        if (!connections[i].is_active) {
            return i;
        }
    }
    return -1;
}

static int find_connection_by_handle(struct bt_conn *conn) {
    for (int i = 0; i < MAX_BLE_CONNECTIONS; i++) {
        if (connections[i].is_active && connections[i].conn == conn) {
            return i;
        }
    }
    return -1;
}

static void update_connection_activity(struct bt_conn *conn) {
    k_mutex_lock(&connections_mutex, K_FOREVER);
    int slot = find_connection_by_handle(conn);
    if (slot >= 0) {
        connections[slot].last_activity = k_uptime_get_32();
    }
    k_mutex_unlock(&connections_mutex);
}

static client_type_t get_connection_type(struct bt_conn *conn) {
    k_mutex_lock(&connections_mutex, K_FOREVER);
    int slot = find_connection_by_handle(conn);
    client_type_t type = (slot >= 0) ? connections[slot].type : CLIENT_TYPE_UNKNOWN;
    k_mutex_unlock(&connections_mutex);
    return type;
}

static void set_connection_type(struct bt_conn *conn, client_type_t type, const char *identifier) {
    k_mutex_lock(&connections_mutex, K_FOREVER);
    int slot = find_connection_by_handle(conn);
    if (slot >= 0) {
        LOG_INF("=== SETTING CONNECTION TYPE ===");
        LOG_INF("Slot: %d", slot);
        LOG_INF("Old type: %d (%s)", connections[slot].type, connections[slot].identifier);
        LOG_INF("New type: %d (%s)", type, identifier);
        
        connections[slot].type = type;
        strncpy(connections[slot].identifier, identifier, sizeof(connections[slot].identifier) - 1);
        connections[slot].identifier[sizeof(connections[slot].identifier) - 1] = '\0';
        connections[slot].last_activity = k_uptime_get_32();
        
        LOG_INF("*** Connection %d identified as %s ***", slot, identifier);
    } else {
        LOG_ERR("Failed to find connection for type setting");
    }
    k_mutex_unlock(&connections_mutex);
}

// Hash and blockchain functions (simplified for space)
static uint32_t simple_hash(const void *data, size_t len) {
    const uint8_t *bytes = (const uint8_t *)data;
    uint32_t hash = 0x811c9dc5;
    for (size_t i = 0; i < len; i++) {
        hash ^= bytes[i];
        hash *= 0x01000193;
    }
    return hash;
}

static int add_transaction(transaction_type_t type, const char *user_id, const char *data) {
    if (system_shutdown_requested && type != TX_SYSTEM_SHUTDOWN) {
        return -ESHUTDOWN;
    }
    
    simple_transaction_t tx;
    tx.timestamp = k_uptime_get_32();
    tx.type = type;
    strncpy(tx.user_id, user_id, MAX_USER_ID_LEN - 1);
    tx.user_id[MAX_USER_ID_LEN - 1] = '\0';
    strncpy(tx.data, data, MAX_DATA_LEN - 1);
    tx.data[MAX_DATA_LEN - 1] = '\0';
    tx.hash = simple_hash(&tx, sizeof(simple_transaction_t) - sizeof(tx.hash));
    
    int ret = k_msgq_put(&pending_tx_queue, &tx, K_NO_WAIT);
    if (ret < 0) {
        LOG_ERR("Transaction queue full");
        return ret;
    }
    LOG_INF("Transaction added: %s - %s", user_id, data);
    return 0;
}

static void trigger_system_shutdown(const char *reason) {
    LOG_ERR("=== INITIATING SYSTEM SHUTDOWN ===");
    LOG_ERR("Reason: %s", reason);
    
    k_mutex_lock(&lockbox_mutex, K_FOREVER);
    g_lockbox_state.tamper_detected = true;
    g_lockbox_state.system_locked = true;
    g_lockbox_state.system_shutdown = true;
    g_lockbox_state.state = STATE_SHUTDOWN;
    k_mutex_unlock(&lockbox_mutex);
    
    system_shutdown_requested = true;
    
    add_transaction(TX_SYSTEM_SHUTDOWN, "SYSTEM", reason);
=
    lock_close();
    
    k_mutex_lock(&connections_mutex, K_FOREVER);
    for (int i = 0; i < MAX_BLE_CONNECTIONS; i++) {
        if (connections[i].is_active) {
            LOG_WRN("Disconnecting BLE client: %s", connections[i].identifier);
            bt_conn_disconnect(connections[i].conn, BT_HCI_ERR_REMOTE_USER_TERM_CONN);
            bt_conn_unref(connections[i].conn);
            memset(&connections[i], 0, sizeof(connection_info_t));
        }
    }
    k_mutex_unlock(&connections_mutex);
    
    bt_le_adv_stop();

    send_alert_to_dashboard("CRITICAL: System shutdown initiated - All operations halted");
    
    LOG_ERR("=== SYSTEM SHUTDOWN COMPLETE ===");
    LOG_ERR("All operations halted. System requires physical reset.");
}

static ssize_t write_tamper_control(struct bt_conn *conn, const struct bt_gatt_attr *attr,
                                   const void *buf, uint16_t len, uint16_t offset, uint8_t flags) {
    if (len != 1) {
        return BT_GATT_ERR(BT_ATT_ERR_INVALID_ATTRIBUTE_LEN);
    }
    
    // Check if system is already shutdown
    k_mutex_lock(&lockbox_mutex, K_FOREVER);
    bool already_shutdown = g_lockbox_state.system_shutdown;
    k_mutex_unlock(&lockbox_mutex);
    
    if (already_shutdown) {
        LOG_WRN("Tamper control write rejected - system already shutdown");
        return BT_GATT_ERR(BT_ATT_ERR_WRITE_NOT_PERMITTED);
    }
    
    if (get_connection_type(conn) == CLIENT_TYPE_UNKNOWN) {
        set_connection_type(conn, CLIENT_TYPE_PC, "PC_CLIENT");
    }
    
    uint8_t tamper_trigger = *(uint8_t*)buf;
    update_connection_activity(conn);
    
    LOG_INF("=== TAMPER CONTROL WRITE ===");
    LOG_INF("Value received: %u", tamper_trigger);
    
    if (tamper_trigger != 0) {
        LOG_ERR("*** TAMPER TRIGGERED VIA BLE ***");
        trigger_system_shutdown("BLE tamper control activated");
    } else {
        LOG_INF("Tamper control: No action (value = 0)");
    }
    
    return len;
}

static ssize_t read_tamper_control(struct bt_conn *conn, const struct bt_gatt_attr *attr,
                                  void *buf, uint16_t len, uint16_t offset) {
    struct {
        uint8_t tamper_detected;
        uint8_t system_locked;
        uint8_t system_shutdown;
        uint32_t timestamp;
    } tamper_status;
    
    k_mutex_lock(&lockbox_mutex, K_FOREVER);
    tamper_status.tamper_detected = g_lockbox_state.tamper_detected ? 1 : 0;
    tamper_status.system_locked = g_lockbox_state.system_locked ? 1 : 0;
    tamper_status.system_shutdown = g_lockbox_state.system_shutdown ? 1 : 0;
    tamper_status.timestamp = k_uptime_get_32();
    k_mutex_unlock(&lockbox_mutex);
    
    update_connection_activity(conn);
    return bt_gatt_attr_read(conn, attr, buf, len, offset, &tamper_status, sizeof(tamper_status));
}
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
int main(void) {
    int err;

    bt_addr_le_t mobile_addr;
    bt_addr_le_from_str(static_mac_str, "random", &mobile_addr);

    err = bt_id_create(&mobile_addr, NULL);
    if (err < 0) {
        LOG_ERR("Failed to set static address");
        return -1;
    }
    
    struct fs_statvfs stats;
    int ret = fs_statvfs("/lfs", &stats);
    if (ret != 0) {
        ret = fs_mount(&blockchain_fs_mount);
        if (ret < 0) {
            LOG_ERR("Failed to mount filesystem: %d", ret);
            return ret;
        }
    }
    
    // Initialize mutexes and queues
    k_mutex_init(&blockchain_mutex);
    k_mutex_init(&lockbox_mutex);
    k_mutex_init(&connections_mutex);
    k_mutex_init(&user_table_mutex);
    k_msgq_init(&pending_tx_queue, (char *)pending_tx_buffer,
                sizeof(simple_transaction_t), 10);
    
    // Initialize states
    memset(&g_lockbox_state, 0, sizeof(lockbox_state_t));
    g_lockbox_state.state = STATE_READY;
    memset(connections, 0, sizeof(connections));
    memset(&g_user_table, 0, sizeof(user_table_t));
    system_shutdown_requested = false;
    
    // Load blockchain
    ret = load_blockchain();
    if (ret < 0) {
        LOG_ERR("Failed to initialize blockchain: %d", ret);
        return ret;
    }
    
    // Validate blockchain
    k_mutex_lock(&blockchain_mutex, K_FOREVER);
    ret = validate_blockchain();
    k_mutex_unlock(&blockchain_mutex);
    
    if (ret < 0) {
        LOG_ERR("Blockchain validation failed - integrity compromised!");
        LOG_WRN("Consider resetting blockchain or investigating corruption");
    } else {
        LOG_INF("Blockchain validation passed - integrity verified");
    }
    
    lock_init();
    
    LOG_INF("Blockchain initialized with %u blocks", g_blockchain.total_blocks);
    LOG_INF("Multi-user system initialized - max users: %d", MAX_USERS);

    // Start Bluetooth
    err = bt_enable(NULL);
    if (err) {
        LOG_ERR("Bluetooth init failed (err %d)", err);
        return -1;
    }

    err = bt_le_adv_start(BT_LE_ADV_CONN_FAST_1, ad, ARRAY_SIZE(ad), NULL, 0);
    if (err) {
        LOG_ERR("Advertising failed (err %d)", err);
        return -1;
    }

    LOG_INF("Advertising started - ready for connections");
    
    observer_start();

    // Main loop
    while (!system_shutdown_requested) {
        k_sleep(K_MSEC(5000));
        
        if (!system_shutdown_requested) {
            k_mutex_lock(&user_table_mutex, K_FOREVER);
            cleanup_expired_passcodes(); // Clean up expired passcodes periodically
            int active_users = g_user_table.active_user_count;
            k_mutex_unlock(&user_table_mutex);
            
            LOG_INF("System running - VOC: %u PPB, Blocks: %u, Active Users: %d", 
                    current_voc_value, g_blockchain.total_blocks, active_users);
        }
    }
    
    // TRIGGER SHUTDOWN
    LOG_ERR("=== TAMPER DETECTED - MELT DOWN ===");

    save_blockchain();
    
    while (1) {
        k_sleep(K_FOREVER);
    }
    
    return 0;
}

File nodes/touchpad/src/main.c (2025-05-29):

#include <zephyr/kernel.h>
#include <zephyr/device.h>
#include <zephyr/drivers/display.h>
#include <zephyr/input/input.h>
#include <zephyr/logging/log.h>
#include <zephyr/bluetooth/bluetooth.h>
#include <zephyr/bluetooth/hci.h>
#include <zephyr/sys/printk.h>

#define ADV_UPDATE_INTERVAL_MS 1000
#define PASSCODE_LENGTH 6

LOG_MODULE_REGISTER(main, LOG_LEVEL_INF);

#define DISPLAY_NODE DT_CHOSEN(zephyr_display)
#define TOUCH_NODE DT_CHOSEN(zephyr_touch)

#define SCREEN_WIDTH  320
#define SCREEN_HEIGHT 240
#define BUTTON_WIDTH  140  // Button width
#define BUTTON_HEIGHT 50   // Button height
#define BUTTON_GAP    10   // Space between buttons

/* Colors (RGB565) */
#define COLOR_BLACK     0x0000
#define COLOR_WHITE     0xFFFF
#define COLOR_GRAY      0x7BEF
#define COLOR_DARK_GRAY 0x39C7
#define COLOR_GREEN     0x07E0
#define COLOR_RED       0xF800
#define COLOR_BLUE      0x001F
#define COLOR_TAN 0xF4A500
#define COLOR_LILAC_PURPLE 0xD8A6F0



/* Button positions */
typedef struct {
    int x, y, w, h;
    int number;
} button_t;

/* Global variables */
static const struct device *display;
static button_t buttons[5]; /* 4 numbers + 1 enter button */
static char passcode[PASSCODE_LENGTH + 1] = {0};
static int passcode_pos = 0;
static int bluetooth_ready = 0;

static char* keypad_mac_str = "DA:AA:BB:BC:CC:FF";

/* Draw a filled rectangle */
static void draw_rect(int x, int y, int w, int h, uint16_t color)
{
    static uint16_t line_buf[SCREEN_WIDTH];
    
    /* Fill line buffer with color */
    for (int i = 0; i < w && i < SCREEN_WIDTH; i++) {
        line_buf[i] = color;
    }
    
    struct display_buffer_descriptor desc = {
        .buf_size = w * 2,
        .width = w,
        .height = 1,
        .pitch = w,
    };
    
    /* Draw rectangle line by line */
    for (int row = 0; row < h; row++) {
        display_write(display, x, y + row, &desc, line_buf);
    }
}

/* Simple 5x7 font bitmap for digits */
static const uint8_t font_5x7[][7] = {
    {0x1F, 0x11, 0x11, 0x11, 0x1F}, /* 0 */
    {0x04, 0x0C, 0x04, 0x04, 0x0E}, /* 1 */
    {0x1F, 0x01, 0x1F, 0x10, 0x1F}, /* 2 */
    {0x1F, 0x01, 0x0F, 0x01, 0x1F}, /* 3 */
    {0x11, 0x11, 0x1F, 0x01, 0x01}, /* 4 */
    {0x1F, 0x10, 0x1F, 0x01, 0x1F}, /* 5 */
    {0x1F, 0x10, 0x1F, 0x11, 0x1F}, /* 6 */
    {0x1F, 0x01, 0x01, 0x01, 0x01}, /* 7 */
    {0x1F, 0x11, 0x1F, 0x11, 0x1F}, /* 8 */
    {0x1F, 0x11, 0x1F, 0x01, 0x1F}, /* 9 */
};

/* Draw a character */
static void draw_char(int x, int y, char c, uint16_t color)
{
    if (c < '0' || c > '9') return;
    
    int digit = c - '0';
    
    for (int row = 0; row < 7; row++) {
        uint8_t line = font_5x7[digit][row];
        for (int col = 0; col < 5; col++) {
            if (line & (1 << (4 - col))) {
                /* Draw pixel */
                uint16_t pixel = color;
                struct display_buffer_descriptor desc = {
                    .buf_size = 2,
                    .width = 1,
                    .height = 1,
                    .pitch = 1,
                };
                display_write(display, x + col, y + row, &desc, &pixel);
            }
        }
    }
}

/* Draw text string */
static void draw_text(int x, int y, const char *text, uint16_t color)
{
    int pos_x = x;
    while (*text) {
        if (*text == '*') {
            /* Draw asterisk for hidden passcode */
            draw_rect(pos_x + 2, y + 3, 2, 2, color);
        } else {
            draw_char(pos_x, y, *text, color);
        }
        pos_x += 6; /* 5 pixel width + 1 spacing */
        text++;
    }
}


// /* Button positions */
// static void init_buttons(void)
// {
//     /* 2x2 grid for numbers 1-4 */
//     for (int i = 0; i < 4; i++) {
//         int row = i / 2;  // Determine row (0 or 1)
//         int col = i % 2;  // Determine column (0 or 1)
        
//         // Shift numbers more to the left
//         buttons[i].x = 20 + col * (BUTTON_WIDTH + BUTTON_GAP);  
//         buttons[i].y = 80 + row * (BUTTON_HEIGHT + BUTTON_GAP); 
//         buttons[i].w = BUTTON_WIDTH;
//         buttons[i].h = BUTTON_HEIGHT;
//         buttons[i].number = i + 1;
//     }
    
//     /* Enter button */
//     buttons[4].x = 90;
//     buttons[4].y = 200;  // Back to original position
//     buttons[4].w = BUTTON_WIDTH;
//     buttons[4].h = BUTTON_HEIGHT;
//     buttons[4].number = -1;  // No number associated with the Enter button
// }






/* Button positions */
static void init_buttons(void)
{
    /* 2x2 grid for numbers 1-4 */
    for (int i = 0; i < 4; i++) {
        int row = i / 2;  // Determine row (0 or 1)
        int col = i % 2;  // Determine column (0 or 1)
        
        // Shift numbers more to the left
        buttons[i].x = 20 + col * (BUTTON_WIDTH + BUTTON_GAP);  
        buttons[i].y = 80 + row * (BUTTON_HEIGHT + BUTTON_GAP); 
        buttons[i].w = BUTTON_WIDTH;
        buttons[i].h = BUTTON_HEIGHT;
        buttons[i].number = i + 1;
    }

    buttons[4].x = 90;
    buttons[4].y = 200; 
    buttons[4].w = BUTTON_WIDTH;
    buttons[4].h = BUTTON_HEIGHT;
    buttons[4].number = -1;  // Use -1 for the CLEAR button (instead of 0 or any number)
}










// /* Draw a button */
// static void draw_button(button_t *btn, bool pressed)
// {
//     uint16_t bg_color = pressed ? COLOR_GRAY : COLOR_DARK_GRAY;
//     uint16_t border_color = COLOR_WHITE;
    
//     /* Draw button background */
//     draw_rect(btn->x, btn->y, btn->w, btn->h, bg_color);
    
//     /* Draw border */
//     draw_rect(btn->x, btn->y, btn->w, 1, border_color); /* top */
//     draw_rect(btn->x, btn->y + btn->h - 1, btn->w, 1, border_color); /* bottom */
//     draw_rect(btn->x, btn->y, 1, btn->h, border_color); /* left */
//     draw_rect(btn->x + btn->w - 1, btn->y, 1, btn->h, border_color); /* right */
    
//     /* Draw button text */
//     if (btn->number >= 1 && btn->number <= 4) {
//         char text[2] = {'0' + btn->number, '\0'};
//         draw_text(btn->x + btn->w / 2 - 3, btn->y + btn->h / 2 - 3, text, COLOR_WHITE);
//     } else if (btn->number == 0) {
//         draw_text(btn->x + 8, btn->y + btn->h / 2 - 3, "ENTER", COLOR_WHITE);
//     }
// }
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

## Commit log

2025-05-27 nialls reference code and basic node frameworks
2025-05-27 box and lid 3d model
    see summary
    [assembly.0001.iam, assembly.iam, assembly2.0003.iam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]
2025-05-28 edits
    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
    [assembly2.0003.iam, assembly2.0004.iam, assembly2.iam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]
2025-05-28 Update with Blockchain code with the actuator working on success and tamper.
2025-05-28 Updates to sensor readingin in bluetooth and uuid sharing.
2025-05-28 threads are blocking each other still
2025-05-29 added verbose function for toggling sensor readings outputs when recieved
2025-05-29 fixed no return on cmd_verbose warning
    [main.c]
2025-05-29 Final commit for James.
    [main.c]
2025-05-29 led on
